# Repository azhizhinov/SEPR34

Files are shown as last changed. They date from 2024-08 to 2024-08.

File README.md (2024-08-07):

## SEPR34
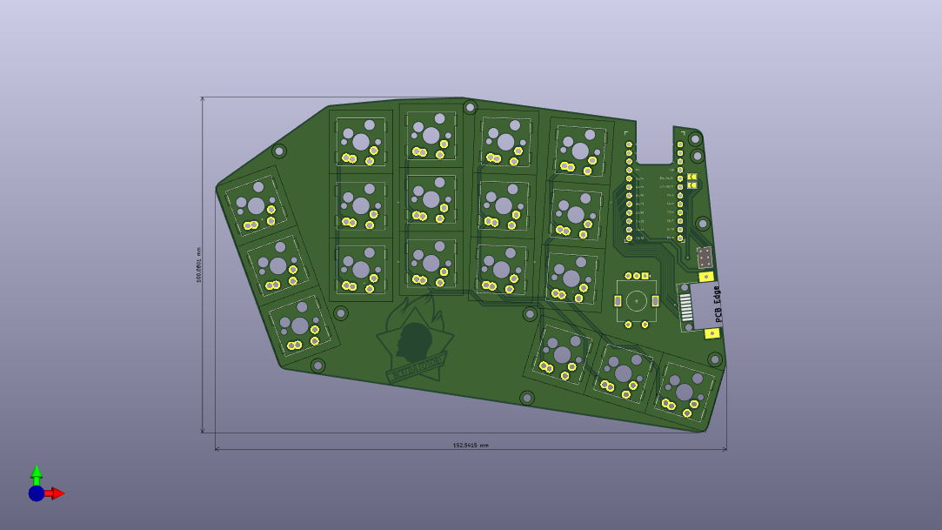
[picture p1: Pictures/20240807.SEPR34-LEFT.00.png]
SEPR34

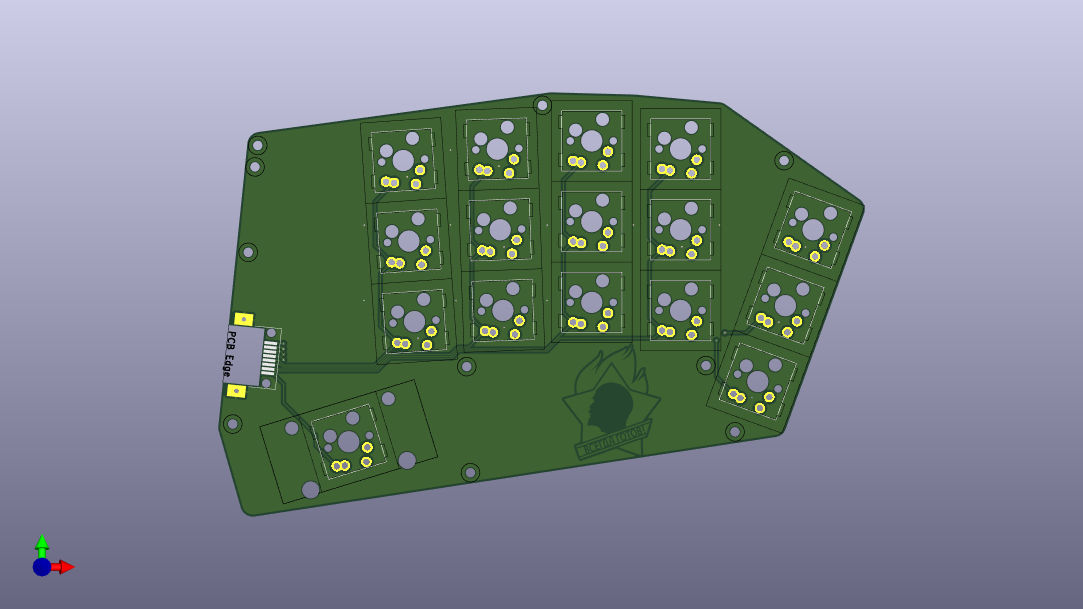
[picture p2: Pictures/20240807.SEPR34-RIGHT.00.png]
SEPR34

The SEPR34 keyboard is a is a [Reviung34split](https://github.com/gtips/reviung/tree/master/reviung34split) fork with single ProMicro, hotswap socket and soldered-in switches support and little addition. The firmware is fully compatible.
This is a WIP.

## Parts
As for the parts list, you will need:
- 2x PCB (The left and right half are different)
- 34 MX or GLP keyswitches
- 34 MX keycaps (MX low-profile for the GLP)
- 34 Hotswap sockets for MX (optional)
- 2x [Ethernet sockets](https://aliexpress.com/item/32974903992.html)
- 1x ProMicro (Warning. I don't have possibility to test ALL clones, so, please, choose cearfully)

## Gerbers
You can find the Gerber files needed to order the PCB on the  directory. Look for the .zip of whatever version you would like!

## Attention
I'm a hobbyist/amateur at best. So there may be things that aren't optimized. So if you decide to use this, then please be advised that I'm not providing any sort of liability and you should exercise some caution. Use these file for your own risk. Thanks Sebastian Stumpf for this text.

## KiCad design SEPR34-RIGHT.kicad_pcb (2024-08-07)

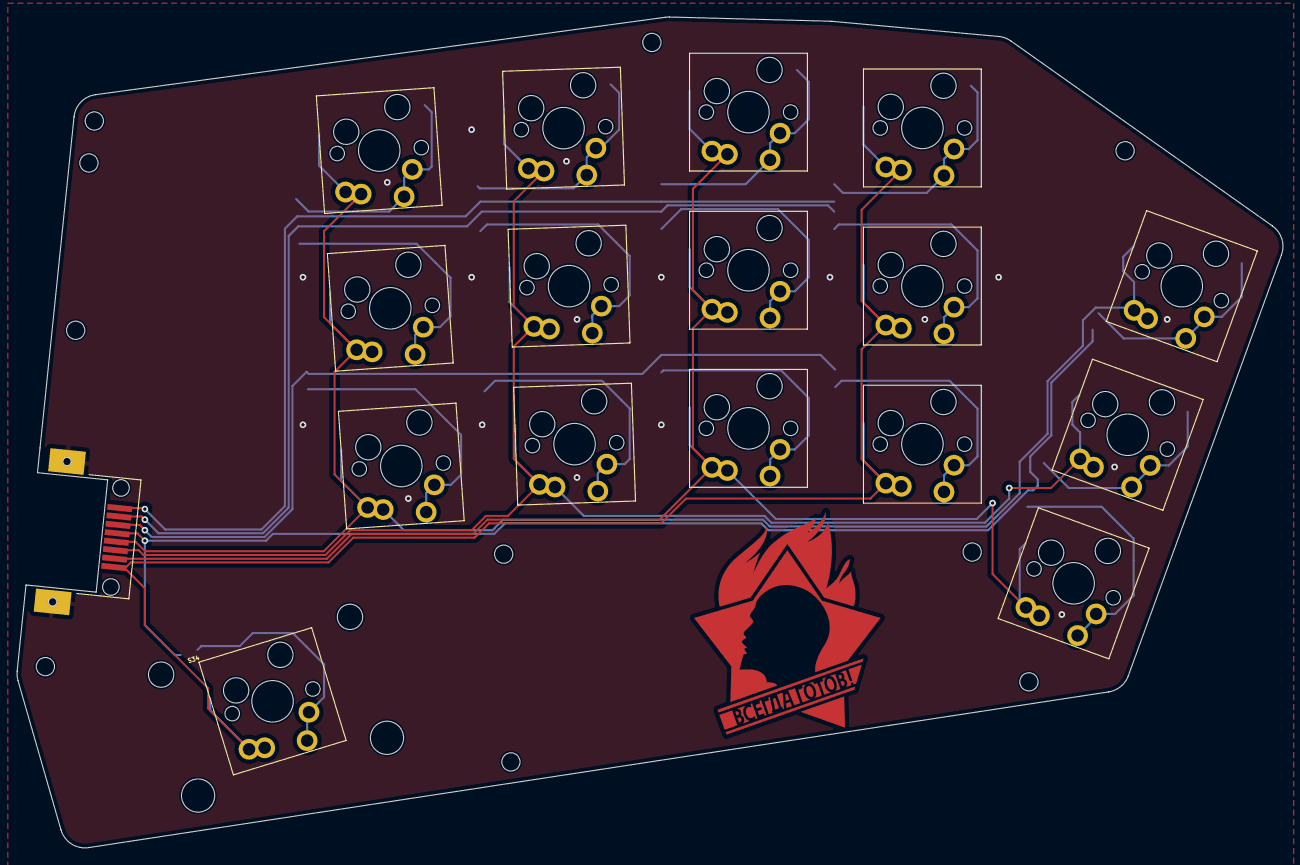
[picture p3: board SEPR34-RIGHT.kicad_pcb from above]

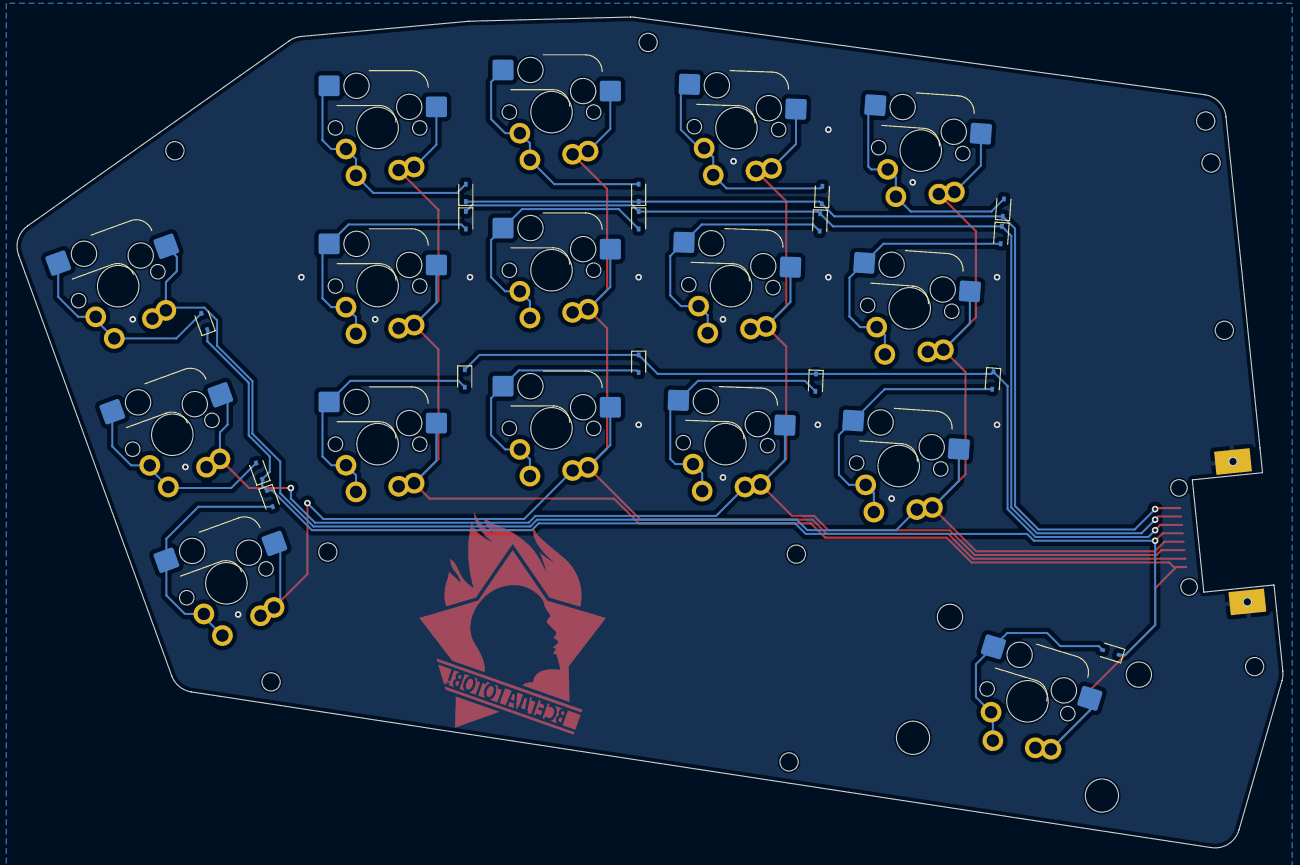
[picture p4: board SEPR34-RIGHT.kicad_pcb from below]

Board: 2 copper layers, 152.5 x 100.1 mm, 43 parts (16 on the bottom side), 24 nets.

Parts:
D19, D20, D21, D22, D23, D24, D25, D26, D27, D28, D29, D30, D31, D32, D33, D34: 1N4148; D_SOD-323
H1, H2, H3, H4, H5: MountingHole; MountingHole_2.2mm_M2
H?: MountingHole; MountingHole_2.2mm_M2
H?#2, H?#3, H?#4, H?#5: MountingHole; MountingHole_2.2mm_M2
J1: 8P8C; SEPOR-RJ45-SOCKET
S19, S20, S21, S22, S23, S24, S25, S26, S27, S28, S29, S30, S31, S32, S33: SWITCH; SEPOR-MX-KS27-HOTSWAP-1U
S34: SW_PUSH_2.0U; SEPOR-MX-KS27-HOTSWAP-2U

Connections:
unnamed: D19.2 (A), S19.2
unnamed: D20.2 (A), S20.2
unnamed: D21.2 (A), S21.2
unnamed: D22.2 (A), S22.2
unnamed: D23.2 (A), S23.2
unnamed: D24.2 (A), S24.2
unnamed: D25.2 (A), S25.2
unnamed: D26.2 (A), S26.2
unnamed: D27.2 (A), S27.2
unnamed: D28.2 (A), S28.2
unnamed: D29.2 (A), S29.2
unnamed: D30.2 (A), S30.2
unnamed: D31.2 (A), S31.2
unnamed: D32.2 (A), S32.2
unnamed: D33.2 (A), S33.2
unnamed: D34.2 (A), S34.2
col5: J1.5, S19.1, S23.1, S27.1, S31.1
col6: J1.6, S20.1, S24.1, S28.1, S32.1
col7: J1.7, S21.1, S25.1, S29.1, S33.1
col8: J1.8, S22.1, S26.1, S30.1, S34.1
row0: D19.1 (K), D20.1 (K), D21.1 (K), D22.1 (K), J1.1
row1: D23.1 (K), D24.1 (K), D25.1 (K), D26.1 (K), J1.2
row2: D27.1 (K), D28.1 (K), D29.1 (K), D30.1 (K), J1.3
row3: D31.1 (K), D32.1 (K), D33.1 (K), D34.1 (K), J1.4

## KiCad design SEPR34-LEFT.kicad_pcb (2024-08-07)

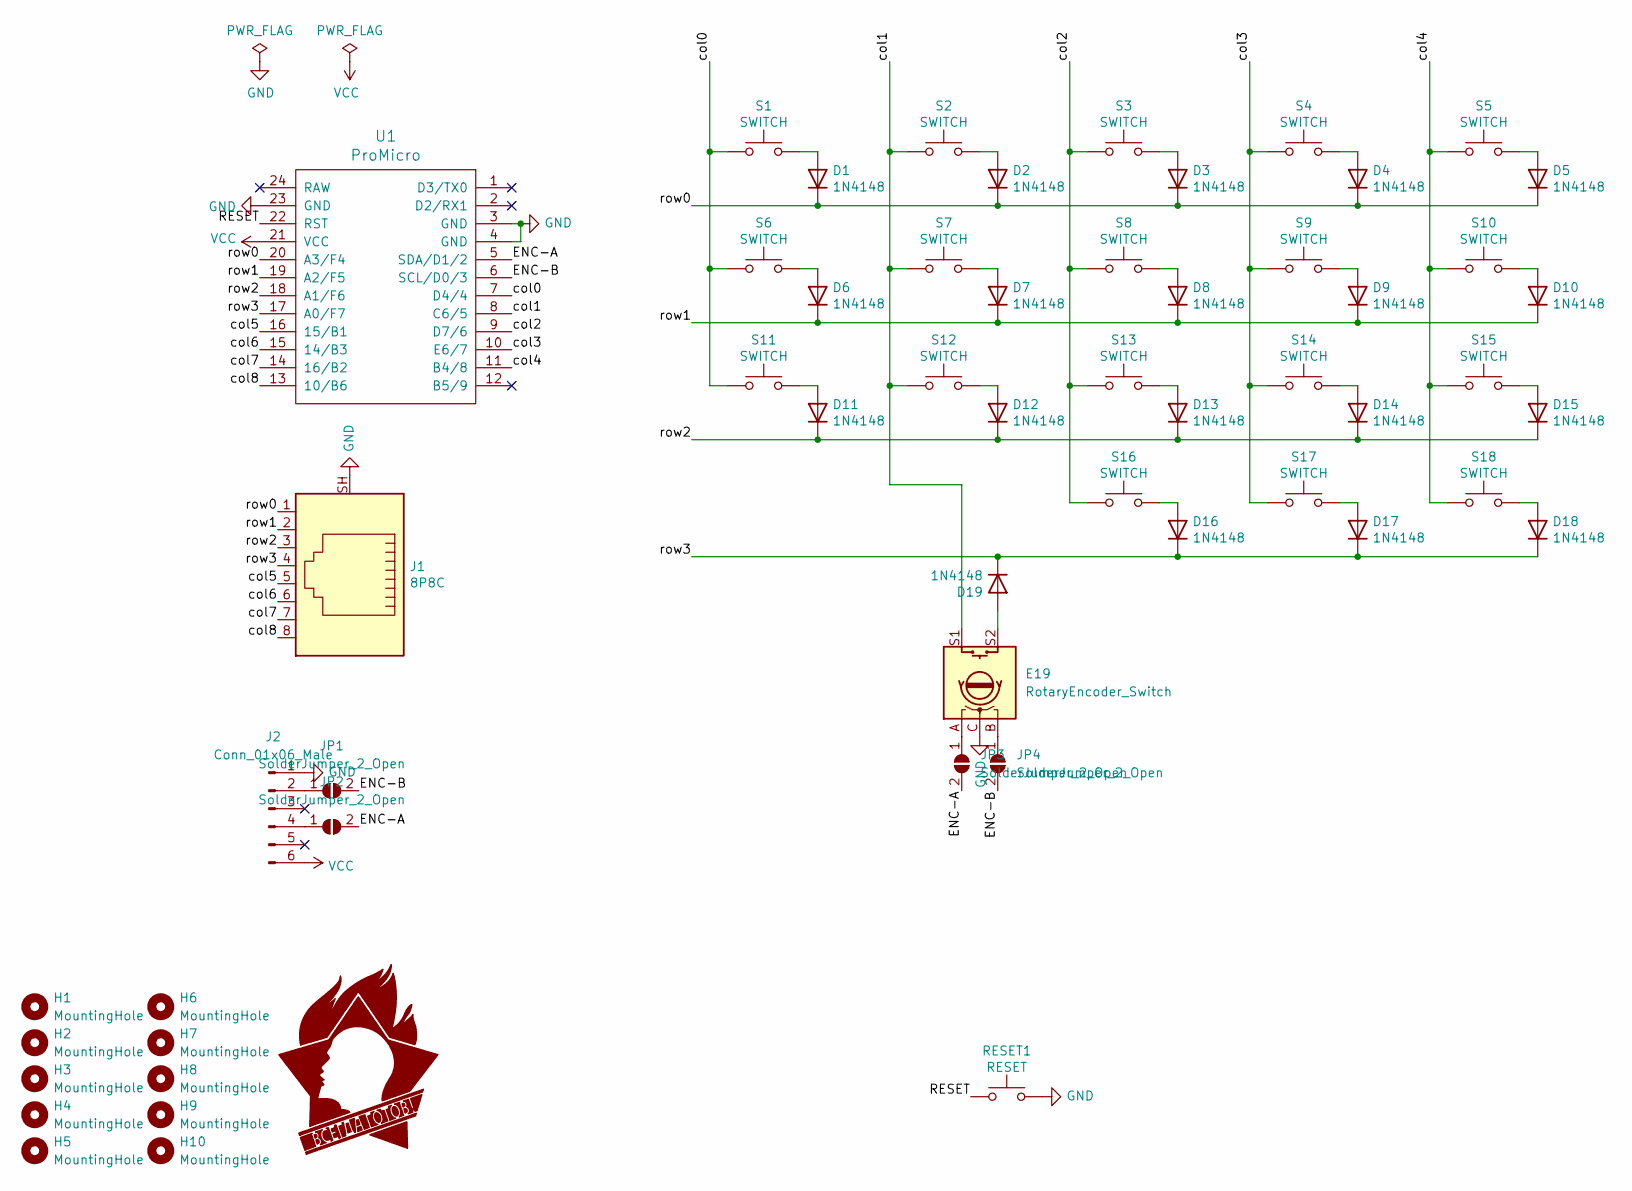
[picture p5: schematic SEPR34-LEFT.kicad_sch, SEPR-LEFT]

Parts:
D1, D2, D3, D4, D5, D6, D7, D8, D9, D10, D11, D12, D13, D14, D15, D16, D17, D18, D19: 1N4148; D_SOD-323
E19: RotaryEncoder_Switch; RotaryEncoder_Alps_EC11E-Switch_Vertical_H20mm
H1, H2, H3, H4, H5, H6, H7, H8, H9, H10: MountingHole; MountingHole_2.2mm_M2
J1: 8P8C; RJ45-HELING-MJ88-XX11-HLSV6-SMD
J2: Conn_01x06_Male; PinHeader_2x03_P2.00mm_Vertical
JP1, JP2, JP3, JP4: SolderJumper_2_Open; SolderJumper-2_P1.3mm_Open_TrianglePad1.0x1.5mm
RESET1: RESET; SW_SPST_TL3342
S1, S2, S3, S4, S5, S6, S7, S8, S9, S10, S11, S12, S13, S14, S15, S16, S17, S18: SWITCH; SEPOR-MX-KS27-HOTSWAP-1U
U1: ProMicro

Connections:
ENC-A: JP2.2 (B), JP3.2 (B), U1.5 (SDA/D1/2)
ENC-B: JP1.2 (B), JP4.2 (B), U1.6 (SCL/D0/3)
GND: E19.C, J1.SH, J2.1, RESET1.2, U1.3 (GND), U1.4 (GND), U1.23 (GND)
unnamed: D1.2 (A), S1.2
unnamed: D2.2 (A), S2.2
unnamed: D3.2 (A), S3.2
unnamed: D4.2 (A), S4.2
unnamed: D5.2 (A), S5.2
unnamed: D6.2 (A), S6.2
unnamed: D7.2 (A), S7.2
unnamed: D8.2 (A), S8.2
unnamed: D9.2 (A), S9.2
unnamed: D10.2 (A), S10.2
unnamed: D11.2 (A), S11.2
unnamed: D12.2 (A), S12.2
unnamed: D13.2 (A), S13.2
unnamed: D14.2 (A), S14.2
unnamed: D15.2 (A), S15.2
unnamed: D16.2 (A), S16.2
unnamed: D17.2 (A), S17.2
unnamed: D18.2 (A), S18.2
unnamed: D19.2 (A), E19.S2
unnamed: E19.A, JP3.1 (A)
unnamed: E19.B, JP4.1 (A)
unnamed: J2.2, JP1.1 (A)
unnamed: J2.4, JP2.1 (A)
VCC: J2.6, U1.21 (VCC)
col0: S1.1, S6.1, S11.1, U1.7 (D4/4)
col1: E19.S1, S2.1, S7.1, S12.1, U1.8 (C6/5)
col2: S3.1, S8.1, S13.1, S16.1, U1.9 (D7/6)
col3: S4.1, S9.1, S14.1, S17.1, U1.10 (E6/7)
col4: S5.1, S10.1, S15.1, S18.1, U1.11 (B4/8)
col5: J1.5, U1.16 (15/B1)
col6: J1.6, U1.15 (14/B3)
col7: J1.7, U1.14 (16/B2)
col8: J1.8, U1.13 (10/B6)
reset: RESET1.1, U1.22 (RST)
row0: D1.1 (K), D2.1 (K), D3.1 (K), D4.1 (K), D5.1 (K), J1.1, U1.20 (A3/F4)
row1: D6.1 (K), D7.1 (K), D8.1 (K), D9.1 (K), D10.1 (K), J1.2, U1.19 (A2/F5)
row2: D11.1 (K), D12.1 (K), D13.1 (K), D14.1 (K), D15.1 (K), J1.3, U1.18 (A1/F6)
row3: D16.1 (K), D17.1 (K), D18.1 (K), D19.1 (K), J1.4, U1.17 (A0/F7)

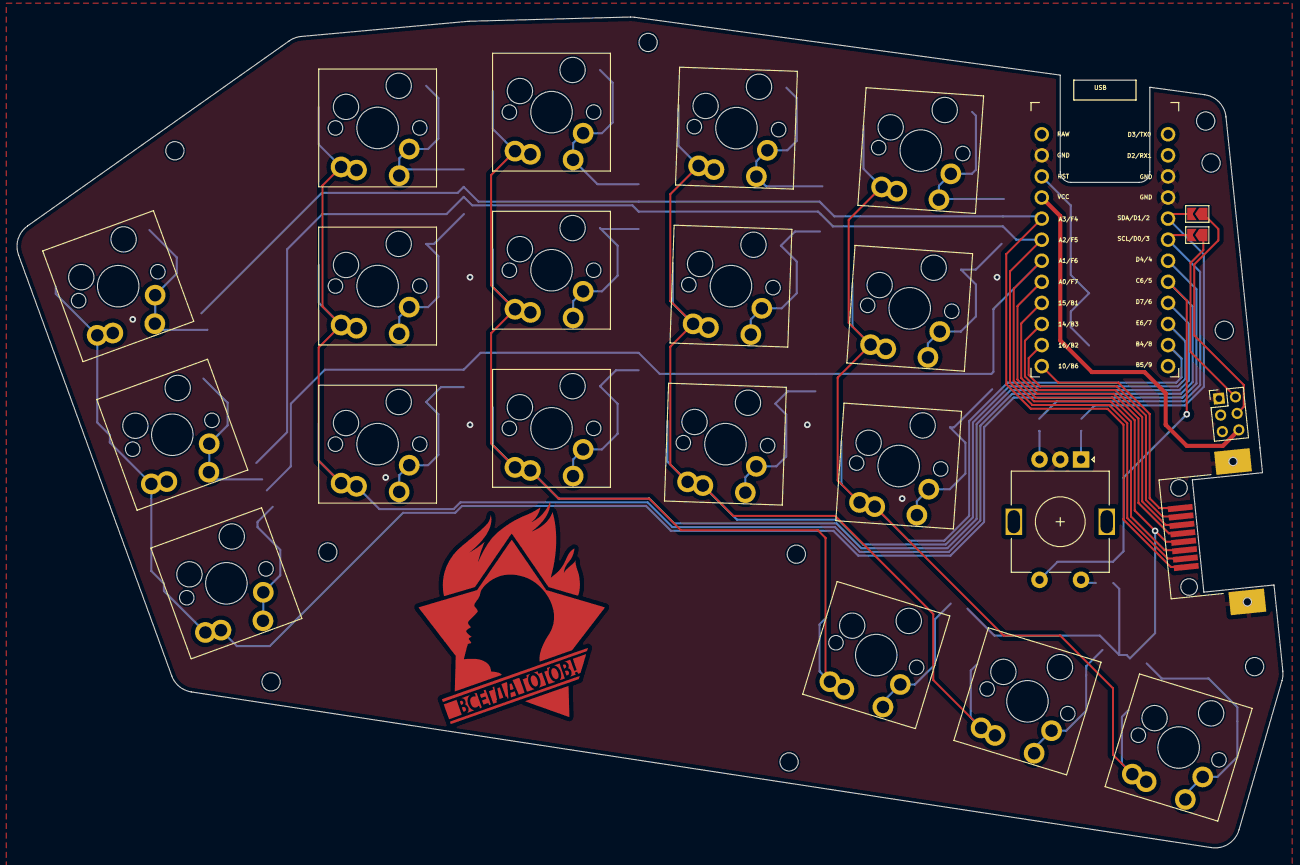
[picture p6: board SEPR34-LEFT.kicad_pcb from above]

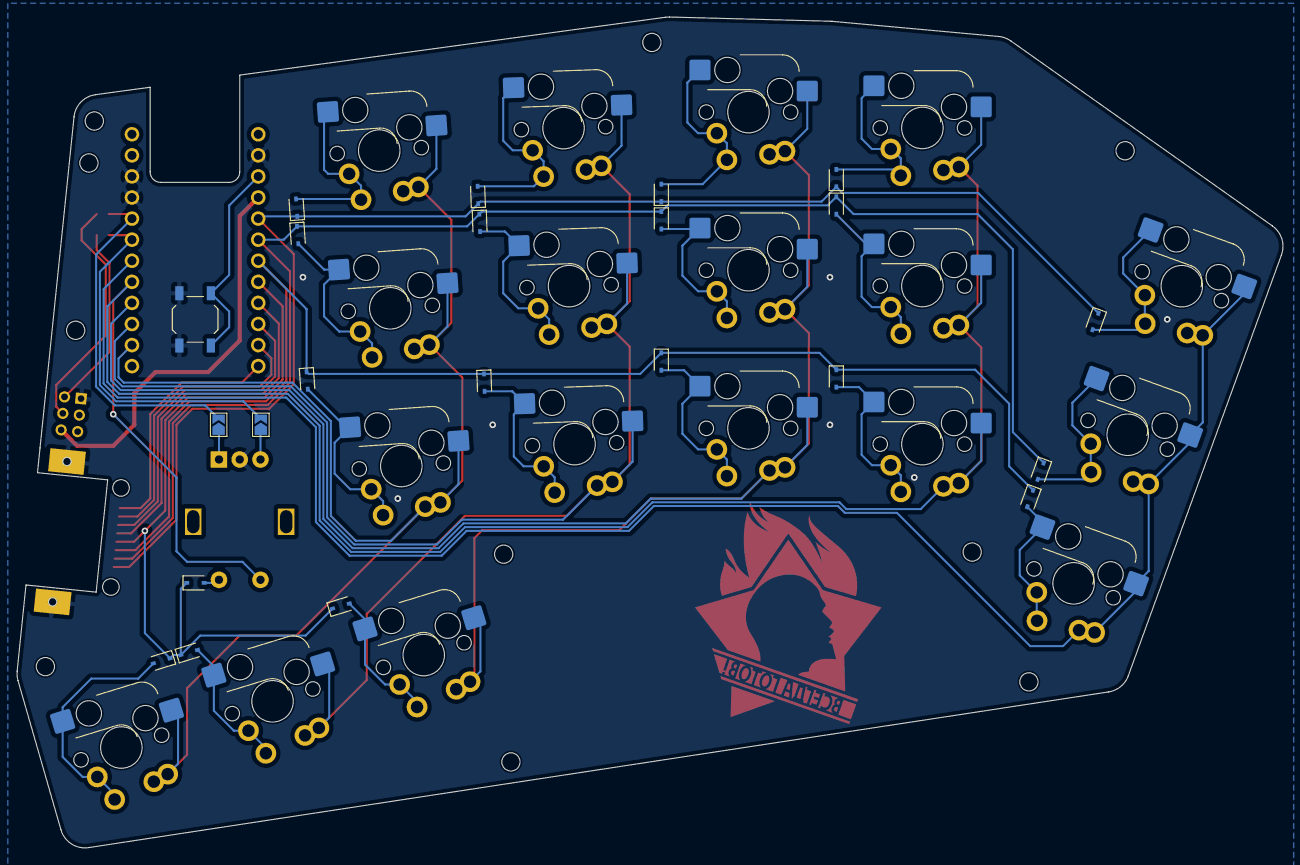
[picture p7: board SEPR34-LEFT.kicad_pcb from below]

Board: 2 copper layers, 152.5 x 100.1 mm, 56 parts (22 on the bottom side), 41 nets.
